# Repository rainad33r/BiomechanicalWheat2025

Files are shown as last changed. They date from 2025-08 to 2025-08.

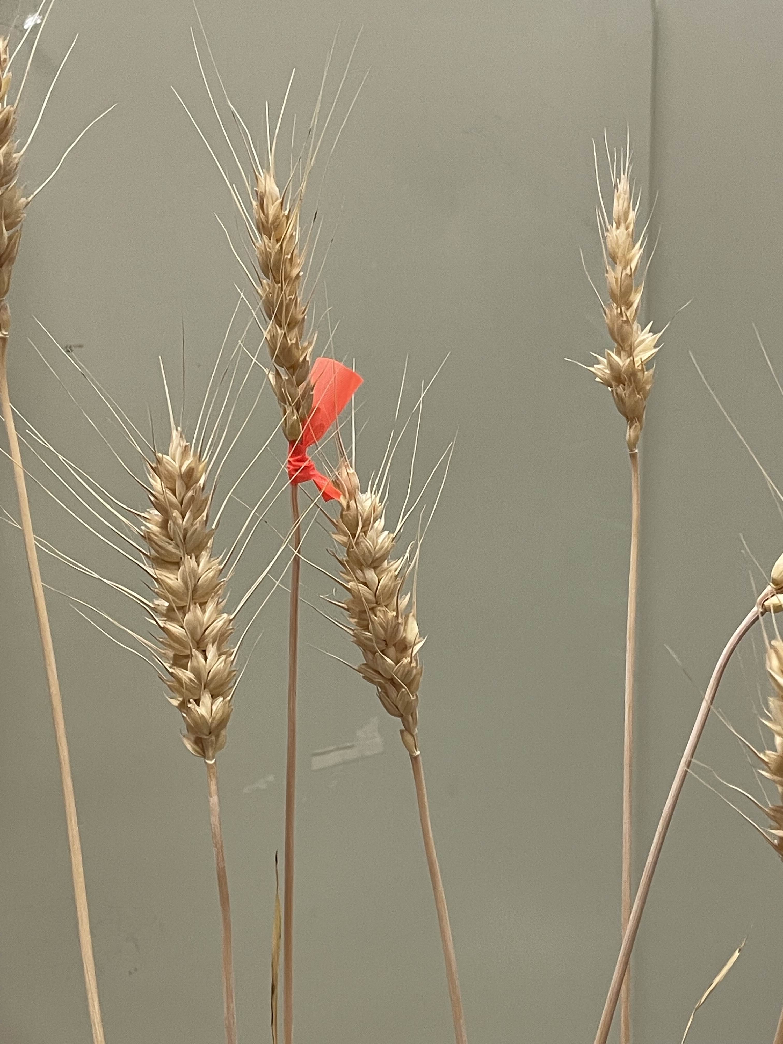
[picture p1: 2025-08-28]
Code/ColourThresholding/ImageThresholding/orangeplt.jpg

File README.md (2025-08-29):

# BiomechanicalWheat2025 USRA Repo
Compiled files of all items worked on over the summer for the wheat testing for lodging parameters. 

You can find my final poster with data from this repo [here](/FinalPoster.pdf)!

## Project Sections
Links will navigate you to specific portions of the project completed  

### Physical Design

For more information on the specifications that went into the physical design, please navigate to the [Physical Design Readme](/PhysicalDesign/README-physicalDesign.md)

> Engineering drawings and references used when modelling the full design. Many are images taken straight from my notebook. </br>[Design Files](/PhysicalDesign/DesignFiles/)

> Includes visual references for machining and STL files of the physical model </br> [Model Files (autodesk inventor)](/PhysicalDesign/modelling)

### Code

> Code used in the field with a Phidget wheatstone bridge, load cell and HUB - Python</br> [Load Cell Acquisition Code](/Code/LoadAcquistion.py)

> Code used to isolate and measure the wheat head motion - MATLAB </br>[Colour Thresholding Code](/Code/ColourThresholding)

> Code used to calculate the cross-sectional area of imaged stems (Images must have a black background to work, images captured with AMScope camera in SpecLab)</br>[Cross-Section Analysis Code](/Code/CrossSectionAnalyzer.m)

> Displays an elastic rod beam with variable damping, stiffness and applied force, code must be implemented with artisynth found [here](https://www.artisynth.org/Main/HomePage)</br>[Simulation Code](/Code/ElasticRod.java)

### Data Collected

For more information on the collected data and the possible next steps resulting from that can be found at this [ReadMe](/CollectedData/README-Data.md). 

> Data collected from the four-point bend test and cross-section analysis </br>[Material Testing](/CollectedData/MaterialsTesting)

> Analysis of material testing data</br>[Material Testing Analysis](/CollectedData/MaterialTestingAnalysis.xlsx)

> Videos and Images of the apparatus in the field </br> [Image Capture](/CollectedData/Video)

> Captured data and analysis of captred load cell data in the field </br> [Load Cell Data](/CollectedData/LoadCellTesting.xlsx)

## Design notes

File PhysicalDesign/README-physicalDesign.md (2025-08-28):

# Important!!

### This file contains helpful references for machining purposes, including size of screws, type of bars and application purposes

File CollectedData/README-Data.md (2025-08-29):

# Data Collection Review

## Image Capture

The videos captured from both the manual and cart showed promise for oscillation of the wheat, however, a few parameters of the design may need to change to for further implementation. 

1. Larger Displacement and larger barrier from external wheat. 
    - The current displacement does not push the wheat nearly as much to enforce a side-to-side oscillation (currently still very front and back) and external wheat can still break through the 'arm' and triangle barriers on the side (slip underneath) further impeding results. 
        - A thicker bar (currently 1'' thick) could be implemented and possibly improve conditions.

2. Secure the main triangle more.
    - While the triangle did work and held its own against the wheat, the frame itself was experiencing lots of motion when the cart moved along with it. 
        - This can be possibly changed with using thicker bars that extend down, rather than the 1'' bars that were used for the entire design.

3. Make variable height easier to achieve.
    - While the curent height was sufficiet for our purposes, extending the traingle and arm further down into the field may show better promise for the actual oscillation rather than the head. 

## Load Cell

Data collected by the load cell was also interesting to disect. With the main portion of the in-field collection oscillating quite a bit on a downward motion. There are a few ideals for the future use of the load cell, if it were to be used with the cart again.

1. Test the possibility of the load cell acting like an accelerometer. 
    - The cart in motion tended to show an increase on the load data collected.
        - This can be tested by simply measuring the load during a speed up and slow down test. 

2. If the load cell is acting like an accelerometer, move the cart at a slower pace. 

Finally, it was found that in combination with the side to side movement of the main design, the load cell would measure that motion as a load instead of the wheat stems. This can be possibly reduced with a more secure design as stated in the previous section.

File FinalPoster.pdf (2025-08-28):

Created by Peter Downing – Educational Media Access and Production © 2011

- Lodging occurs when too much force is exerted upon the stem of a crop, usually in the form of strong storm winds.

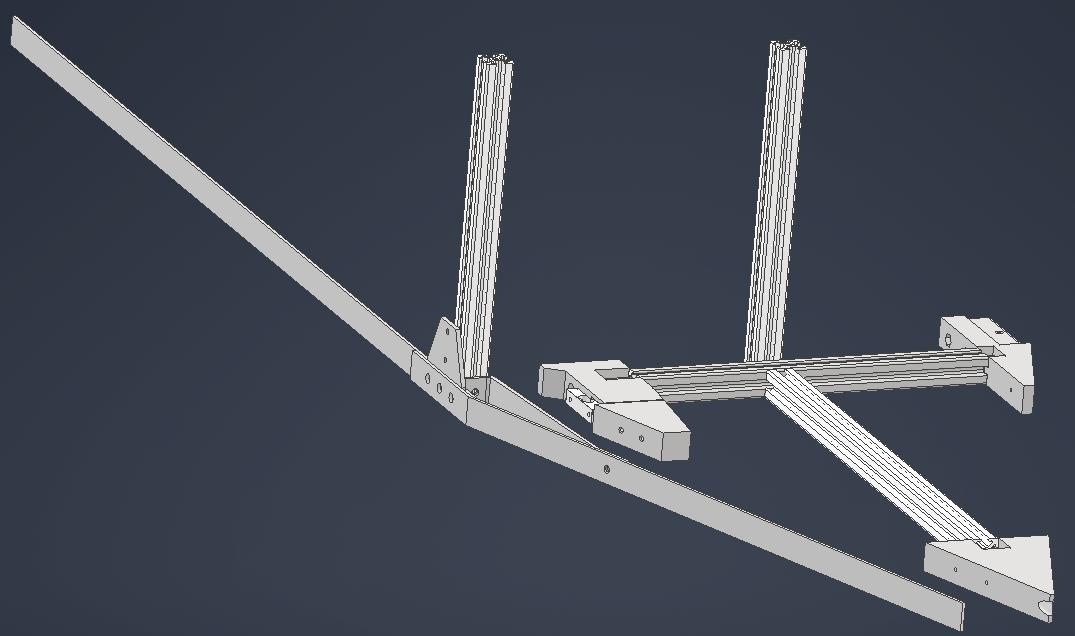
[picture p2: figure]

1-2

- To understand the factors contributing to lodging of a crop, we must first understand the biomechanics of the wheat stem
- A system is needed to measure these biomechanics

Introduction & Background

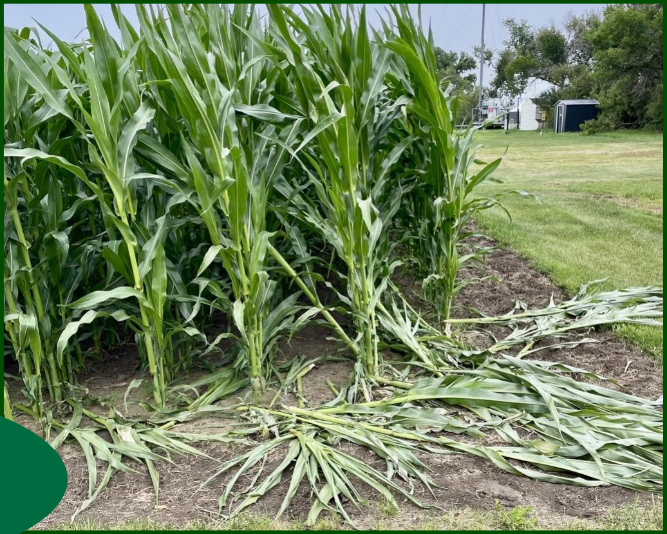
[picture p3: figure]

- To properly determine the biomechanics of wheat, two components are used: A simulation of a wheat stem with variable physical properties based on material testing, and a mechanical design used together with the Agriculture and Agri-food Canada cart in the field.
- Materials testing (four-point bend test and cross-sectional analysis) were conducted on several live and dead wheat stems to simulate varying moisture content in the crop.
- A simulation of a stem was created using the parameters found in the material testing, which could then be used to simulate oscillation of a crop.
- The mechanical design focused on perturbing the wheat a large enough distance to

Overview

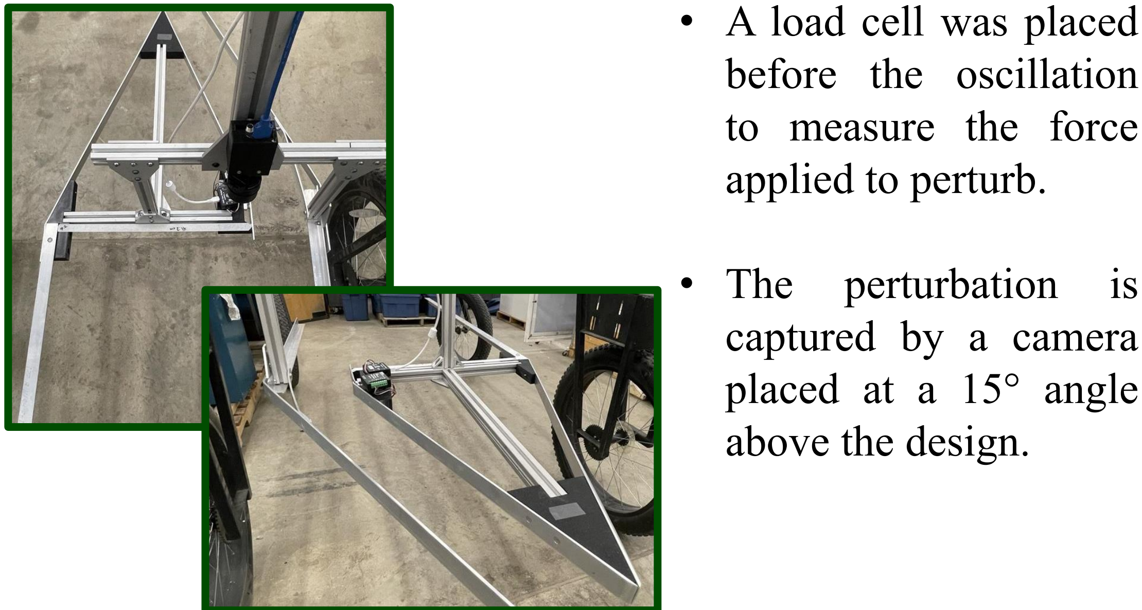
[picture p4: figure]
• A load cell was placed before the oscillation to measure the force applied to perturb.; • The; perturbation; captured by a camera placed at a 15° angle above the design.

Materials Testing

Mechanical Design | Analysis

Measured Test Oscillation Pattern

Next Steps
For future development of this research, the implementation of the mechanical design, the ‘wheat separator’, in conjunction with the AAFC cart is required for field data collection. Using the data found in the field and the previously discussed equations, a set of parameters that describe the biomechanics of wheat in the field can be developed. Comparing the field data with the simulated and test data allows for the verification of the validity of the captured data. Using the found parameters from the field in the simulation allows for the exploration of these characterizations further where variability in the physical properties of the wheat is straightforward.

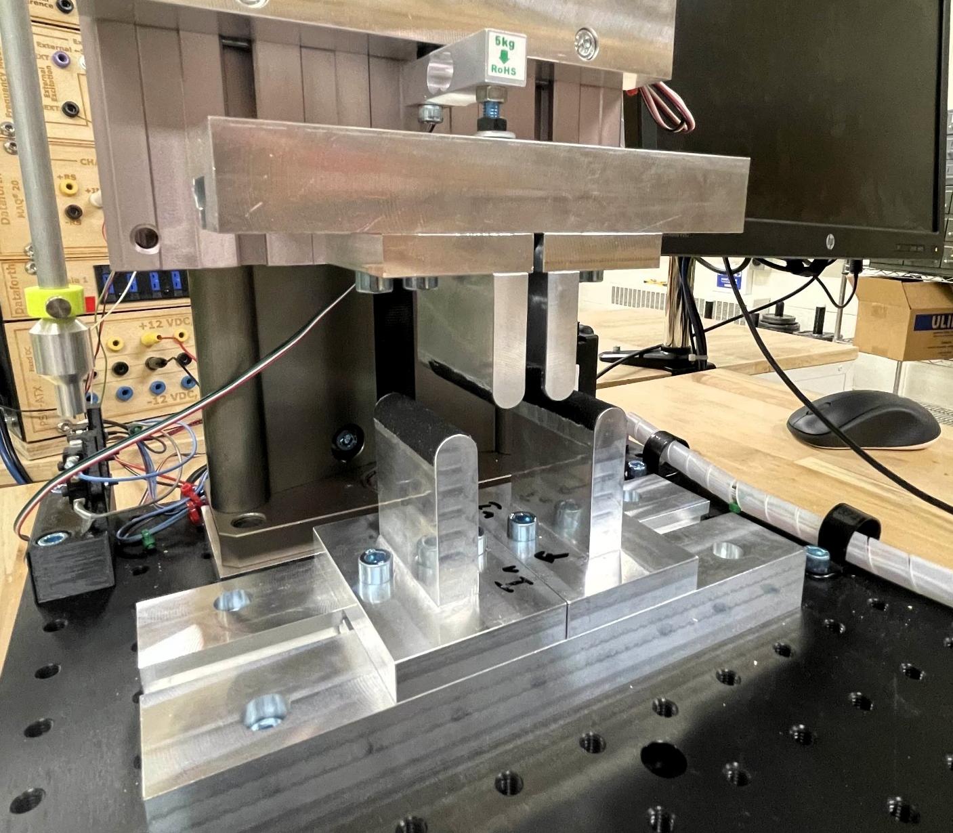
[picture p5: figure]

References

1. Sterling, M., Baker, C. J., Berry, P. M., & Wade, A. (2003a). An experimental investigation of the lodging of wheat. Agricultural and Forest Meteorology, 119(3–4), 149–165. https://doi.org/10.1016/s0168-1923(03)00140-0
2. Mohammadi, M., Finnan, J., Sterling, M., & Baker, C. (2020). A calibrated oat lodging model compared with agronomic measurements. Field Crops Research, 255, 107784. https://doi.org/10.1016/j.fcr.2020.107784
3. Dolovich, A. (2025, May). Bending of a Wheat Stem According to Euler-Bernoulli Beam Theory. Lecture.
4. O’Dogherty, M. J., Huber, J. A., Dyson, J., & Marshall, C. J. (1995). A study of the physical and mechanical properties of wheat straw. Journal of Agricultural Engineering Research, 62(2), 133–142. https://doi.org/10.1006/jaer.1995.1072

# OWL: Oscillation of Wheat to determine Lodging Parameters

# Raina Owen, Ian Stavness & Scott Noble

## Departments of Computer Science and Mechanical Engineering

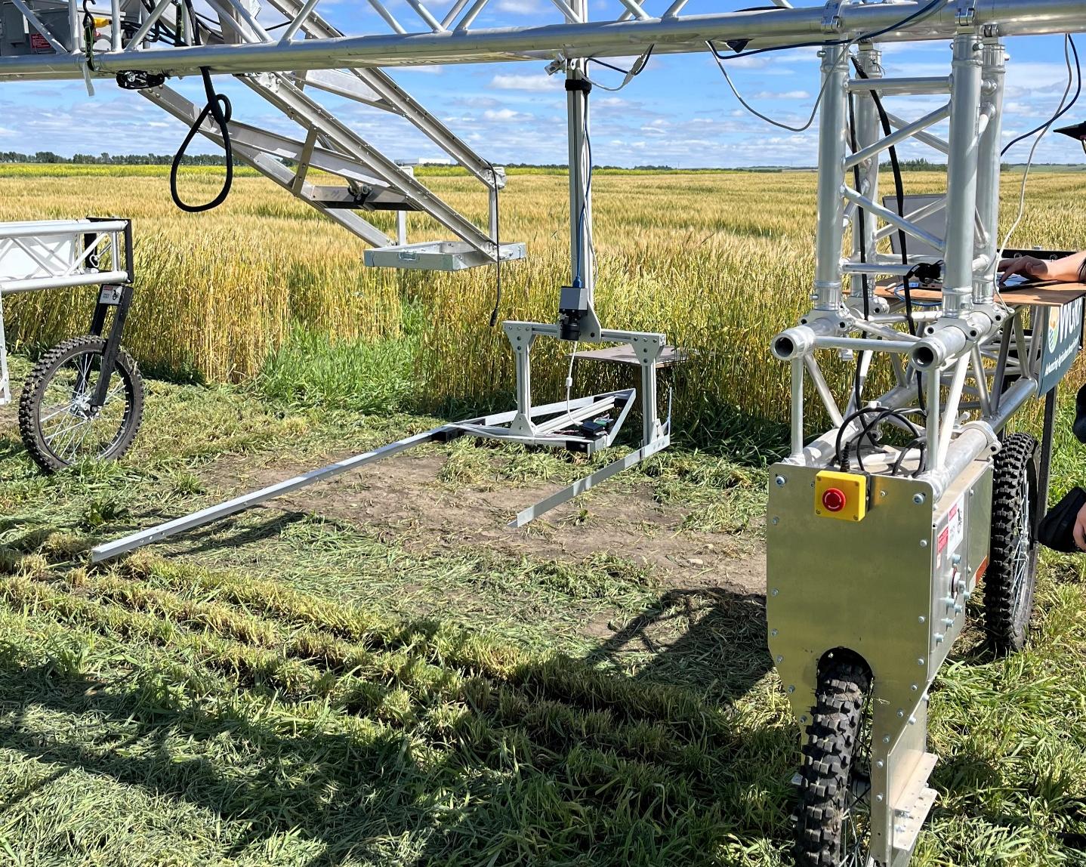
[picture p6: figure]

A cross-section of every stem that was load tested was then cut and captured with a microscope camera. This allowed us to accurately calculate the inner and outer radii of each stem.

- A 4-point bend test was
conducted to calculate the maximum stress.
- Friction tape was placed on each point to prevent
any sliding of the samples.
- Stems were tested in long sections, separated at the nodes

Simulation Capture

Example of Lodging in Corn

Cross-Sectional Capture

Four-Point Bend Test Setup

A | triangle | base
component and a
detached ‘arm’
were modelled to
contain | and
separate a select
few stems of wheat
to | simplify | the
collection of data .

Full Design of Separator

Modelled Design of Separator

Acknowledgements

Cross-Section Imaging Setup

Using the following equations, values were found for stiffness, stress and oscillation frequency.

3

Allan Dolovich – Beam theory and material testing assistance. Reisha Peters – Cross-sectional capture and analyzing assistance. Keith Halcro – General assembly and data collection support. SpecLab Team & BIGlab Team

The data found in the material testing was used to calculate stiffness and force parameters that would then be inputted into biomechanical stem model as shown below. The oscillation patterns of the design and simulation could then be compared.

But Why Care
About Lodging?

Lodged wheat is difficult to harvest and can drastically reduce the total yield.

- By exploring the
mechanics of a simulated
stem and using a
mechanical system to
capture data, the
biomechanics can be
properly determined.

k =

F
δ

=

3EI
L

3

## σmax =

4PL
πr

3

ωi =

βi

4EI
ρA

Values for modulus of elasticity and density were researched.

4

induce oscillation
while measuring the
force required to push
it to that point and
then capturing the
oscillation that
followed. The design
is made to enforce a
manageable sample
size.

AAFC Cart Attachment

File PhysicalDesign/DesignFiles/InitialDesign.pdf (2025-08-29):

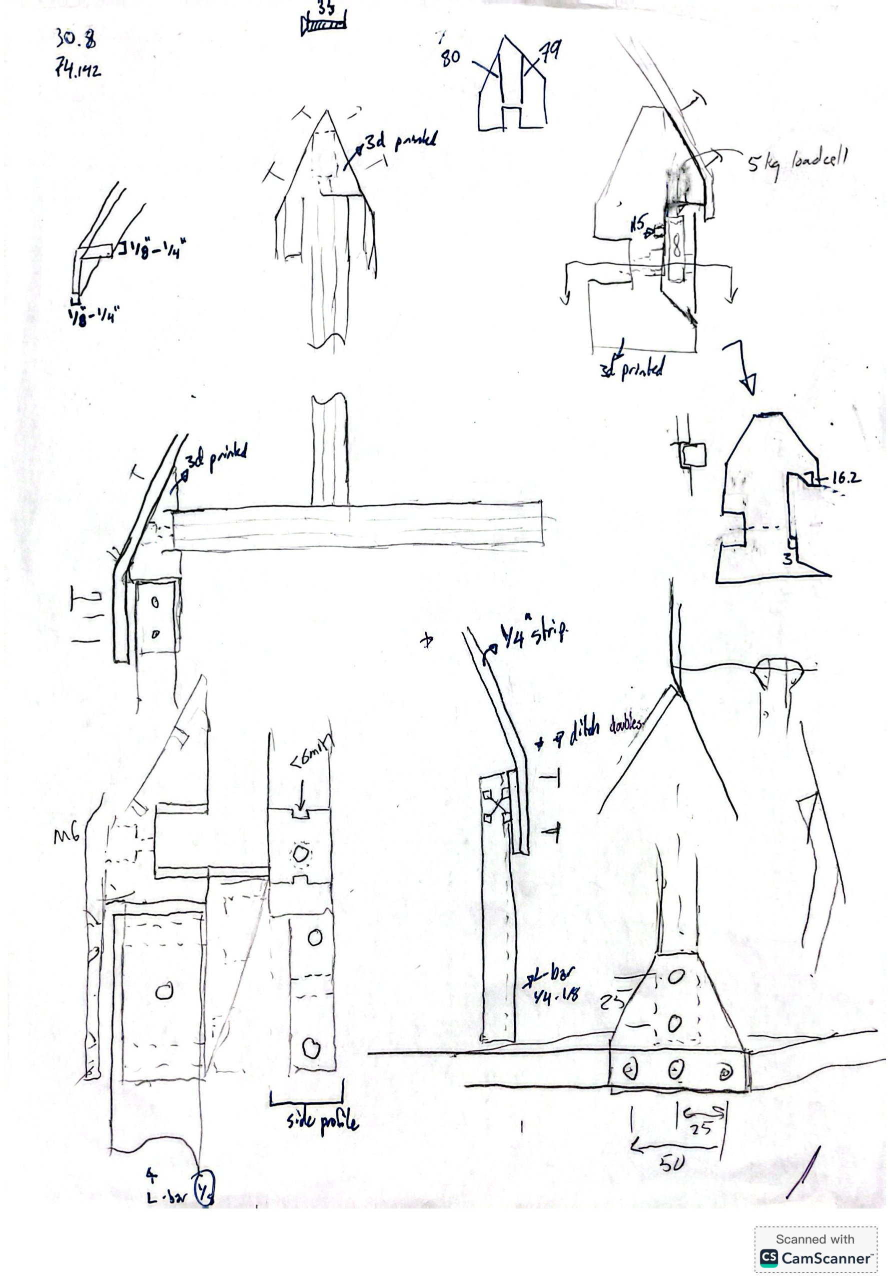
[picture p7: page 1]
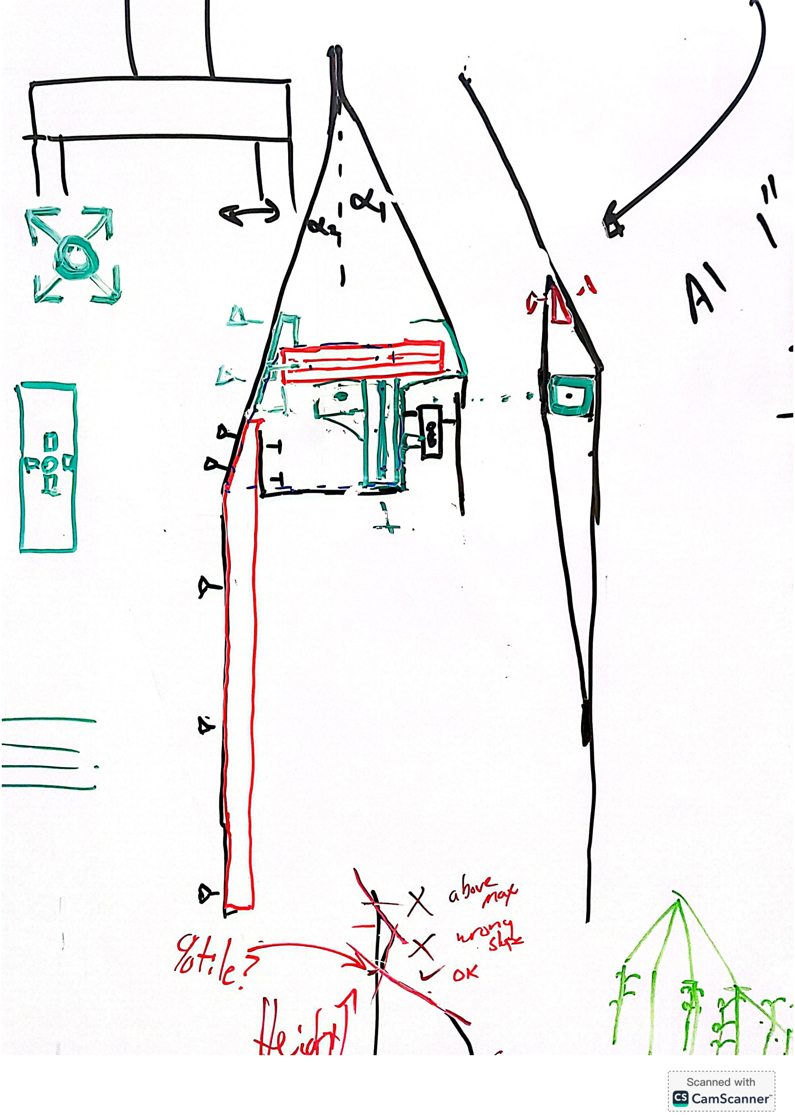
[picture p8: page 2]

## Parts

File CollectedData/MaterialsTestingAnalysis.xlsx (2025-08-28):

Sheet: DeadStems Load
Time (s) | Load Cell (N) | DeadStemLong | Time (s) | Load (N) | D105 | time | Load | D160 | time | Load | D178 | Time | Load | D258 | Time | Load | D1602 | time |  | Name: | Maximum Load
0.000 | 0.000 |  | 0.000 | 0.033 |  | 0.000 | -0.144 |  | 0.000 | 6.191 |  | 0.000 | -0.008 |  | 0.000 | -0.009 |  | 0.000 | -0.007 | D1 | 5.652
0.100 | -0.002 |  | 0.100 | 0.035 |  | 0.100 | -0.144 |  | 0.100 | 6.277 |  | 0.100 | -0.054 |  | 0.100 | -0.009 |  | 0.100 | -0.008 | DeadStemLong | 6.231
0.200 | -0.003 |  | 0.200 | 0.031 |  | 0.200 | -0.143 |  | 0.200 | 6.339 |  | 0.200 | -0.106 |  | 0.200 | 0.013 |  | 0.200 | -0.010 | D105 | 7.599
0.300 | -0.006 |  | 0.300 | 0.033 |  | 0.300 | 1.807 |  | 0.300 | 6.370 |  | 0.300 | -0.130 |  | 0.300 | -0.001 |  | 0.300 | -0.008 | D160 | 6.132
0.400 | -0.006 |  | 0.400 | 0.032 |  | 0.400 | 3.381 |  | 0.400 | 6.395 |  | 0.400 | -0.136 |  | 0.400 | -0.002 |  | 0.400 | -0.020 | D178 | 4.748
0.500 | -0.004 |  | 0.500 | 0.036 |  | 0.500 | 4.357 |  | 0.500 | 6.416 |  | 0.500 | -0.139 |  | 0.500 | -0.009 |  | 0.500 | -0.015 | D258 | 7.722
0.600 | -0.003 |  | 0.600 | 0.034 |  | 0.600 | 5.069 |  | 0.600 | 6.432 |  | 0.600 | -0.118 |  | 0.600 | -0.006 |  | 0.600 | -0.015 | D1602 | 8.507
0.700 | -0.006 |  | 0.700 | 0.038 |  | 0.700 | 5.509 |  | 0.700 | 6.444 |  | 0.700 | -0.140 |  | 0.700 | -0.004 |  | 0.700 | -0.012
0.800 | -0.004 |  | 0.800 | 0.037 |  | 0.800 | 5.830 |  | 0.800 | 6.453 |  | 0.800 | -0.141 |  | 0.800 | -0.009 |  | 0.800 | -0.014
0.900 | -0.006 |  | 0.900 | 0.038 |  | 0.900 | 6.043 |  | 0.900 | 6.454 |  | 0.900 | -0.172 |  | 0.900 | -0.009 |  | 0.900 | -0.012
1.000 | -0.004 |  | 1.000 | 0.035 |  | 1.000 | 6.173 |  | 1.000 | 6.456 |  | 1.000 | -0.184 |  | 1.000 | -0.006 |  | 1.000 | -0.009
1.100 | -0.005 |  | 1.100 | 0.038 |  | 1.100 | 6.264 |  | 1.100 | 6.456 |  | 1.100 | -0.187 |  | 1.100 | -0.009 |  | 1.100 | -0.011
1.200 | -0.005 |  | 1.200 | 0.034 |  | 1.200 | 6.325 |  | 1.200 | 6.434 |  | 1.200 | -0.195 |  | 1.200 | -0.005 |  | 1.200 | -0.009
1.300 | -0.005 |  | 1.300 | 0.035 |  | 1.300 | 6.371 |  | 1.300 | 6.443 |  | 1.300 | -0.209 |  | 1.300 | -0.006 |  | 1.300 | -0.007
1.400 | -0.005 |  | 1.400 | 0.032 |  | 1.400 | 6.397 |  | 1.400 | 6.439 |  | 1.400 | -0.230 |  | 1.400 | -0.008 |  | 1.400 | -0.004
1.500 | -0.008 |  | 1.500 | 0.036 |  | 1.500 | 6.418 |  | 1.500 | 6.424 |  | 1.500 | -0.240 |  | 1.500 | 0.005 |  | 1.500 | 0.000
1.600 | -0.006 |  | 1.600 | 0.034 |  | 1.600 | 6.437 |  | 1.600 | 6.402 |  | 1.600 | -0.259 |  | 1.600 | -0.002 |  | 1.600 | -0.007
1.700 | -0.006 |  | 1.700 | 0.036 |  | 1.700 | 6.446 |  | 1.700 | 6.371 |  | 1.700 | -0.288 |  | 1.700 | -0.003 |  | 1.700 | -0.003
1.800 | -0.007 |  | 1.800 | 0.033 |  | 1.800 | 6.453 |  | 1.800 | 6.322 |  | 1.800 | -0.308 |  | 1.800 | -0.008 |  | 1.800 | -0.004
1.900 | -0.008 |  | 1.900 | 0.036 |  | 1.900 | 6.454 |  | 1.900 | 6.254 |  | 1.900 | -0.321 |  | 1.900 | -0.004 |  | 1.900 | -0.007
2.000 | -0.006 |  | 2.000 | 0.033 |  | 2.000 | 6.456 |  | 2.000 | 6.171 |  | 2.000 | -0.341 |  | 2.000 | -0.009 |  | 2.000 | -0.005
2.100 | -0.005 |  | 2.100 | 0.034 |  | 2.100 | 6.456 |  | 2.100 | 6.057 |  | 2.100 | -0.401 |  | 2.100 | -0.020 |  | 2.100 | -0.006
2.200 | -0.006 |  | 2.200 | 0.031 |  | 2.200 | 6.453 |  | 2.200 | 5.933 |  | 2.200 | -0.421 |  | 2.200 | -0.010 |  | 2.200 | 0.007
2.300 | -0.007 |  | 2.300 | 0.033 |  | 2.300 | 6.457 |  | 2.300 | 5.775 |  | 2.300 | -0.436 |  | 2.300 | -0.015 |  | 2.300 | 0.003
2.400 | -0.007 |  | 2.400 | 0.031 |  | 2.400 | 6.455 |  | 2.400 | 5.614 |  | 2.400 | -0.454 |  | 2.400 | -0.013 |  | 2.400 | 0.000
2.500 | -0.006 |  | 2.500 | 0.032 |  | 2.500 | 6.454 |  | 2.500 | 5.416 |  | 2.500 | -0.455 |  | 2.500 | -0.008 |  | 2.500 | -0.001
2.600 | -0.005 |  | 2.600 | 0.030 |  | 2.600 | 6.455 |  | 2.600 | 5.222 |  | 2.600 | -0.467 |  | 2.600 | -0.007 |  | 2.600 | -0.003
2.700 | -0.003 |  | 2.700 | 0.033 |  | 2.700 | 6.453 |  | 2.700 | 4.991 |  | 2.700 | -0.478 |  | 2.700 | -0.006 |  | 2.700 | 0.000
2.800 | -0.005 |  | 2.800 | 0.031 |  | 2.800 | 6.457 |  | 2.800 | 4.766 |  | 2.800 | -0.493 |  | 2.800 | -0.008 |  | 2.800 | -0.003
2.900 | -0.004 |  | 2.900 | 0.034 |  | 2.900 | 6.456 |  | 2.900 | 4.510 |  | 2.900 | -0.512 |  | 2.900 | -0.007 |  | 2.900 | -0.002
3.000 | -0.004 |  | 3.000 | 0.023 |  | 3.000 | 6.459 |  | 3.000 | 4.259 |  | 3.000 | -0.529 |  | 3.000 | -0.008 |  | 3.000 | -0.004
3.100 | -0.003 |  | 3.100 | 0.011 |  | 3.100 | 6.461 |  | 3.100 | 3.983 |  | 3.100 | -0.552 |  | 3.100 | -0.013 |  | 3.100 | -0.005
3.200 | -0.003 |  | 3.200 | -0.017 |  | 3.200 | 6.457 |  | 3.200 | 3.726 |  | 3.200 | -0.578 |  | 3.200 | -0.009 |  | 3.200 | -0.004
3.300 | -0.002 |  | 3.300 | -0.087 |  | 3.300 | 6.462 |  | 3.300 | 3.439 |  | 3.300 | -0.630 |  | 3.300 | -0.014 |  | 3.300 | -0.004
3.400 | -0.003 |  | 3.400 | -0.145 |  | 3.400 | 6.460 |  | 3.400 | 3.180 |  | 3.400 | -0.655 |  | 3.400 | -0.010 |  | 3.400 | -0.002
3.500 | -0.004 |  | 3.500 | -0.230 |  | 3.500 | 6.458 |  | 3.500 | 2.890 |  | 3.500 | -0.687 |  | 3.500 | -0.008 |  | 3.500 | -0.003
3.600 | -0.004 |  | 3.600 | -0.311 |  | 3.600 | 6.459 |  | 3.600 | 2.610 |  | 3.600 | -0.752 |  | 3.600 | -0.012 |  | 3.600 | -0.005
3.700 | -0.004 |  | 3.700 | -0.403 |  | 3.700 | 6.454 |  | 3.700 | 2.343 |  | 3.700 | -0.781 |  | 3.700 | -0.007 |  | 3.700 | -0.002
3.800 | -0.005 |  | 3.800 | -0.491 |  | 3.800 | 6.455 |  | 3.800 | 2.055 |  | 3.800 | -0.810 |  | 3.800 | -0.011 |  | 3.800 | -0.006
3.900 | -0.003 |  | 3.900 | -0.589 |  | 3.900 | 6.455 |  | 3.900 | 1.787 |  | 3.900 | -0.845 |  | 3.900 | -0.008 |  | 3.900 | -0.003
4.000 | -0.001 |  | 4.000 | -0.678 |  | 4.000 | 6.450 |  | 4.000 | 1.492 |  | 4.000 | -0.911 |  | 4.000 | -0.006 |  | 4.000 | -0.003
4.100 | -0.002 |  | 4.100 | -0.781 |  | 4.100 | 6.453 |  | 4.100 | 1.225 |  | 4.100 | -0.948 |  | 4.100 | -0.009 |  | 4.100 | -0.004
4.200 | -0.003 |  | 4.200 | -0.882 |  | 4.200 | 6.446 |  | 4.200 | 0.932 |  | 4.200 | -1.060 |  | 4.200 | -0.006 |  | 4.200 | -0.003
4.300 | -0.003 |  | 4.300 | -0.969 |  | 4.300 | 6.448 |  | 4.300 | 0.667 |  | 4.300 | -1.142 |  | 4.300 | -0.009 |  | 4.300 | -0.009
4.400 | -0.004 |  | 4.400 | -1.075 |  | 4.400 | 6.449 |  | 4.400 | 0.377 |  | 4.400 | -1.182 |  | 4.400 | -0.011 |  | 4.400 | -0.010
4.500 | -0.002 |  | 4.500 | -1.178 |  | 4.500 | 6.448 |  | 4.500 | 0.116 |  | 4.500 | -1.226 |  | 4.500 | -0.008 |  | 4.500 | -0.012
4.600 | -0.001 |  | 4.600 | -1.284 |  | 4.600 | 6.448 |  | 4.600 | -0.153 |  | 4.600 | -1.268 |  | 4.600 | -0.014 |  | 4.600 | -0.015
4.700 | -0.003 |  | 4.700 | -1.389 |  | 4.700 | 6.444 |  | 4.700 | -0.409 |  | 4.700 | -1.316 |  | 4.700 | -0.013 |  | 4.700 | -0.016
4.800 | -0.002 |  | 4.800 | -1.495 |  | 4.800 | 6.444 |  | 4.800 | -0.676 |  | 4.800 | -1.410 |  | 4.800 | -0.022 |  | 4.800 | -0.024
4.900 | -0.002 |  | 4.900 | -1.599 |  | 4.900 | 6.444 |  | 4.900 | -0.925 |  | 4.900 | -1.454 |  | 4.900 | -0.036 |  | 4.900 | -0.032
5.000 | -0.002 |  | 5.000 | -1.711 |  | 5.000 | 6.444 |  | 5.000 | -1.194 |  | 5.000 | -1.501 |  | 5.000 | -0.046 |  | 5.000 | -0.046
5.100 | -0.002 |  | 5.100 | -1.826 |  | 5.100 | 6.437 |  | 5.100 | -1.430 |  | 5.100 | -1.549 |  | 5.100 | -0.069 |  | 5.100 | -0.066
5.200 | -0.003 |  | 5.200 | -1.932 |  | 5.200 | 6.430 |  | 5.200 | -1.694 |  | 5.200 | -1.598 |  | 5.200 | -0.091 |  | 5.200 | -0.083
5.300 | -0.003 |  | 5.300 | -2.035 |  | 5.300 | 6.431 |  | 5.300 | -1.922 |  | 5.300 | -1.650 |  | 5.300 | -0.121 |  | 5.300 | -0.112
5.400 | -0.004 |  | 5.400 | -2.157 |  | 5.400 | 6.426 |  | 5.400 | -2.170 |  | 5.400 | -1.703 |  | 5.400 | -0.161 |  | 5.400 | -0.143
5.500 | -0.004 |  | 5.500 | -2.270 |  | 5.500 | 6.426 |  | 5.500 | -2.406 |  | 5.500 | -1.753 |  | 5.500 | -0.195 |  | 5.500 | -0.174
5.600 | -0.004 |  | 5.600 | -2.381 |  | 5.600 | 6.420 |  | 5.600 | -2.614 |  | 5.600 | -1.859 |  | 5.600 | -0.242 |  | 5.600 | -0.218
5.700 | -0.001 |  | 5.700 | -2.496 |  | 5.700 | 6.405 |  | 5.700 | -2.845 |  | 5.700 | -1.913 |  | 5.700 | -0.291 |  | 5.700 | -0.258
5.800 | -0.004 |  | 5.800 | -2.609 |  | 5.800 | 6.404 |  | 5.800 | -3.046 |  | 5.800 | -1.966 |  | 5.800 | -0.346 |  | 5.800 | -0.301
5.900 | -0.004 |  | 5.900 | -2.737 |  | 5.900 | 6.397 |  | 5.900 | -3.247 |  | 5.900 | -2.015 |  | 5.900 | -0.407 |  | 5.900 | -0.351
6.000 | -0.004 |  | 6.000 | -2.904 |  | 6.000 | 6.391 |  | 6.000 | -3.457 |  | 6.000 | -2.069 |  | 6.000 | -0.473 |  | 6.000 | -0.410
6.100 | -0.002 |  | 6.100 | -3.002 |  | 6.100 | 6.388 |  | 6.100 | -3.641 |  | 6.100 | -2.119 |  | 6.100 | -0.540 |  | 6.100 | -0.473
6.200 | 0.000 |  | 6.200 | -3.084 |  | 6.200 | 6.374 |  | 6.200 | -3.842 |  | 6.200 | -2.285 |  | 6.200 | -0.615 |  | 6.200 | -0.554
6.300 | 0.000 |  | 6.300 | -3.180 |  | 6.300 | 6.365 |  | 6.300 | -4.013 |  | 6.300 | -2.336 |  | 6.300 | -0.686 |  | 6.300 | -0.637
6.400 | -0.001 |  | 6.400 | -3.274 |  | 6.400 | 6.348 |  | 6.400 | -4.193 |  | 6.400 | -2.392 |  | 6.400 | -0.771 |  | 6.400 | -0.731
6.500 | 0.000 |  | 6.500 | -3.368 |  | 6.500 | 6.340 |  | 6.500 | -4.363 |  | 6.500 | -2.443 |  | 6.500 | -0.847 |  | 6.500 | -0.841
6.600 | -0.002 |  | 6.600 | -3.468 |  | 6.600 | 6.329 |  | 6.600 | -4.508 |  | 6.600 | -2.494 |  | 6.600 | -0.938 |  | 6.600 | -0.959
6.700 | -0.002 |  | 6.700 | -3.567 |  | 6.700 | 6.314 |  | 6.700 | -4.663 |  | 6.700 | -2.558 |  | 6.700 | -1.021 |  | 6.700 | -1.077
6.800 | -0.003 |  | 6.800 | -3.675 |  | 6.800 | 6.303 |  | 6.800 | -4.792 |  | 6.800 | -2.613 |  | 6.800 | -1.117 |  | 6.800 | -1.210
6.900 | -0.002 |  | 6.900 | -3.768 |  | 6.900 | 6.284 |  | 6.900 | -4.931 |  | 6.900 | -2.676 |  | 6.900 | -1.212 |  | 6.900 | -1.340
7.000 | -0.004 |  | 7.000 | -3.876 |  | 7.000 | 6.265 |  | 7.000 | -5.051 |  | 7.000 | -2.732 |  | 7.000 | -1.310 |  | 7.000 | -1.490
7.100 | -0.005 |  | 7.100 | -3.967 |  | 7.100 | 6.257 |  | 7.100 | -5.180 |  | 7.100 | -2.793 |  | 7.100 | -1.403 |  | 7.100 | -1.627
7.200 | -0.005 |  | 7.200 | -4.071 |  | 7.200 | 6.244 |  | 7.200 | -5.289 |  | 7.200 | -2.908 |  | 7.200 | -1.506 |  | 7.200 | -1.785
7.300 | -0.004 |  | 7.300 | -4.167 |  | 7.300 | 6.237 |  | 7.300 | -5.393 |  | 7.300 | -2.960 |  | 7.300 | -1.601 |  | 7.300 | -1.933
7.400 | -0.001 |  | 7.400 | -4.262 |  | 7.400 | 6.232 |  | 7.400 | -5.484 |  | 7.400 | -3.018 |  | 7.400 | -1.707 |  | 7.400 | -2.090
7.500 | -0.003 |  | 7.500 | -4.362 |  | 7.500 | 6.222 |  | 7.500 | -5.569 |  | 7.500 | -3.075 |  | 7.500 | -1.807 |  | 7.500 | -2.243
7.600 | -0.003 |  | 7.600 | -4.451 |  | 7.600 | 6.222 |  | 7.600 | -5.647 |  | 7.600 | -3.193 |  | 7.600 | -1.916 |  | 7.600 | -2.403
7.700 | -0.002 |  | 7.700 | -4.556 |  | 7.700 | 6.213 |  | 7.700 | -5.726 |  | 7.700 | -3.249 |  | 7.700 | -2.025 |  | 7.700 | -2.559
7.800 | -0.002 |  | 7.800 | -4.639 |  | 7.800 | 6.202 |  | 7.800 | -5.791 |  | 7.800 | -3.306 |  | 7.800 | -2.129 |  | 7.800 | -2.730
7.900 | 0.000 |  | 7.900 | -4.737 |  | 7.900 | 6.179 |  | 7.900 | -5.852 |  | 7.900 | -3.368 |  | 7.900 | -2.238 |  | 7.900 | -2.882
8.000 | 0.002 |  | 8.000 | -4.826 |  | 8.000 | 6.147 |  | 8.000 | -5.896 |  | 8.000 | -3.421 |  | 8.000 | -2.344 |  | 8.000 | -3.065
8.100 | 0.000 |  | 8.100 | -4.914 |  | 8.100 | 6.117 |  | 8.100 | -5.938 |  | 8.100 | -3.478 |  | 8.100 | -2.459 |  | 8.100 | -3.222
8.200 | 0.000 |  | 8.200 | -5.008 |  | 8.200 | 6.076 |  | 8.200 | -5.975 |  | 8.200 | -3.528 |  | 8.200 | -2.564 |  | 8.200 | -3.407
8.300 | -0.001 |  | 8.300 | -5.090 |  | 8.300 | 6.036 |  | 8.300 | -6.008 |  | 8.300 | -3.582 |  | 8.300 | -2.689 |  | 8.300 | -3.585
8.400 | -0.002 |  | 8.400 | -5.175 |  | 8.400 | 5.986 |  | 8.400 | -6.052 |  | 8.400 | -3.640 |  | 8.400 | -2.798 |  | 8.400 | -3.755
8.500 | -0.002 |  | 8.500 | -5.269 |  | 8.500 | 5.927 |  | 8.500 | -6.079 |  | 8.500 | -3.694 |  | 8.500 | -2.905 |  | 8.500 | -3.944
8.600 | -0.003 |  | 8.600 | -5.341 |  | 8.600 | 5.861 |  | 8.600 | -6.105 |  | 8.600 | -3.804 |  | 8.600 | -3.013 |  | 8.600 | -4.116
8.700 | -0.001 |  | 8.700 | -5.434 |  | 8.700 | 5.790 |  | 8.700 | -6.122 |  | 8.700 | -3.914 |  | 8.700 | -3.118 |  | 8.700 | -4.307
8.800 | -0.002 |  | 8.800 | -5.503 |  | 8.800 | 5.707 |  | 8.800 | -6.131 |  | 8.800 | -3.967 |  | 8.800 | -3.226 |  | 8.800 | -4.469
8.900 | -0.002 |  | 8.900 | -5.588 |  | 8.900 | 5.626 |  | 8.900 | -6.132 |  | 8.900 | -4.075 |  | 8.900 | -3.339 |  | 8.900 | -4.655
9.000 | -0.002 |  | 9.000 | -5.650 |  | 9.000 | 5.536 |  | 9.000 | -6.123 |  | 9.000 | -4.124 |  | 9.000 | -3.442 |  | 9.000 | -4.819
9.100 | -0.002 |  | 9.100 | -5.718 |  | 9.100 | 5.449 |  | 9.100 | -6.104 |  | 9.100 | -4.220 |  | 9.100 | -3.559 |  | 9.100 | -4.991
9.200 | -0.001 |  | 9.200 | -5.784 |  | 9.200 | 5.353 |  | 9.200 | -6.069 |  | 9.200 | -4.315 |  | 9.200 | -3.661 |  | 9.200 | -5.154
9.300 | -0.001 |  | 9.300 | -5.842 |  | 9.300 | 5.259 |  | 9.300 | -6.031 |  | 9.300 | -4.400 |  | 9.300 | -3.787 |  | 9.300 | -5.322
9.400 | -0.002 |  | 9.400 | -5.907 |  | 9.400 | 5.166 |  | 9.400 | -5.988 |  | 9.400 | -4.481 |  | 9.400 | -3.895 |  | 9.400 | -5.487
9.500 | -0.003 |  | 9.500 | -5.953 |  | 9.500 | 5.066 |  | 9.500 | -5.938 |  | 9.500 | -4.516 |  | 9.500 | -4.014 |  | 9.500 | -5.664
9.600 | -0.005 |  | 9.600 | -6.010 |  | 9.600 | 4.981 |  | 9.600 | -5.890 |  | 9.600 | -4.556 |  | 9.600 | -4.131 |  | 9.600 | -5.821
9.700 | -0.006 |  | 9.700 | -6.035 |  | 9.700 | 4.927 |  | 9.700 | -5.841 |  | 9.700 | -4.584 |  | 9.700 | -4.245 |  | 9.700 | -5.994
9.800 | -0.005 |  | 9.800 | -6.080 |  | 9.800 | 4.896 |  | 9.800 | -5.790 |  | 9.800 | -4.623 |  | 9.800 | -4.361 |  | 9.800 | -6.141
9.900 | -0.004 |  | 9.900 | -6.112 |  | 9.900 | 4.879 |  | 9.900 | -5.746 |  | 9.900 | -4.641 |  | 9.900 | -4.483 |  | 9.900 | -6.308
10.000 | -0.002 |  | 10.000 | -6.142 |  | 10.000 | 4.872 |  | 10.000 | -5.696 |  | 10.000 | -4.679 |  | 10.000 | -4.589 |  | 10.000 | -6.450
10.100 | -0.003 |  | 10.100 | -6.176 |  | 10.100 | 4.866 |  | 10.100 | -5.650 |  | 10.100 | -4.692 |  | 10.100 | -4.714 |  | 10.100 | -6.603
10.200 | -0.003 |  | 10.200 | -6.193 |  | 10.200 | 4.864 |  | 10.200 | -5.601 |  | 10.200 | -4.709 |  | 10.200 | -4.821 |  | 10.200 | -6.751
10.300 | -0.003 |  | 10.300 | -6.218 |  | 10.300 | 4.869 |  | 10.300 | -5.561 |  | 10.300 | -4.720 |  | 10.300 | -4.942 |  | 10.300 | -6.881
10.400 | -0.002 |  | 10.400 | -6.222 |  | 10.400 | 4.870 |  | 10.400 | -5.520 |  | 10.400 | -4.730 |  | 10.400 | -5.053 |  | 10.400 | -7.025
10.500 | 0.000 |  | 10.500 | -6.231 |  | 10.500 | 4.874 |  | 10.500 | -5.467 |  | 10.500 | -4.740 |  | 10.500 | -5.160 |  | 10.500 | -7.147
10.600 | -0.001 |  | 10.600 | -6.222 |  | 10.600 | 4.910 |  | 10.600 | -5.413 |  | 10.600 | -4.742 |  | 10.600 | -5.272 |  | 10.600 | -7.280
10.700 | -0.002 |  | 10.700 | -6.204 |  | 10.700 | 4.971 |  | 10.700 | -5.361 |  | 10.700 | -4.748 |  | 10.700 | -5.376 |  | 10.700 | -7.393
10.800 | -0.002 |  | 10.800 | -6.182 |  | 10.800 | 5.063 |  | 10.800 | -5.301 |  | 10.800 | -4.736 |  | 10.800 | -5.483 |  | 10.800 | -7.517
10.900 | -0.004 |  | 10.900 | -6.134 |  | 10.900 | 5.167 |  | 10.900 | -5.260 |  | 10.900 | -4.714 |  | 10.900 | -5.595 |  | 10.900 | -7.631
11.000 | -0.002 |  | 11.000 | -6.098 |  | 11.000 | 5.277 |  | 11.000 | -5.217 |  | 11.000 | -4.608 |  | 11.000 | -5.696 |  | 11.000 | -7.742
11.100 | -0.002 |  | 11.100 | -6.037 |  | 11.100 | 5.400 |  | 11.100 | -5.186 |  | 11.100 | -4.588 |  | 11.100 | -5.812 |  | 11.100 | -7.847
11.200 | -0.001 |  | 11.200 | -5.985 |  | 11.200 | 5.513 |  | 11.200 | -5.137 |  | 11.200 | -4.524 |  | 11.200 | -5.907 |  | 11.200 | -7.946
11.300 | 0.000 |  | 11.300 | -5.923 |  | 11.300 | 5.640 |  | 11.300 | -5.093 |  | 11.300 | -4.499 |  | 11.300 | -6.021 |  | 11.300 | -8.030
11.400 | -0.001 |  | 11.400 | -5.853 |  | 11.400 | 5.751 |  | 11.400 | -5.051 |  | 11.400 | -4.481 |  | 11.400 | -6.123 |  | 11.400 | -8.121
11.500 | -0.011 |  | 11.500 | -5.792 |  | 11.500 | 5.868 |  | 11.500 | -5.011 |  | 11.500 | -4.455 |  | 11.500 | -6.218 |  | 11.500 | -8.186
11.600 | -0.021 |  | 11.600 | -5.726 |  | 11.600 | 5.973 |  | 11.600 | -4.976 |  | 11.600 | -4.443 |  | 11.600 | -6.317 |  | 11.600 | -8.261
11.700 | -0.056 |  | 11.700 | -5.667 |  | 11.700 | 6.072 |  | 11.700 | -4.944 |  | 11.700 | -4.423 |  | 11.700 | -6.407 |  | 11.700 | -8.313
11.800 | -0.119 |  | 11.800 | -5.612 |  | 11.800 | 6.157 |  | 11.800 | -4.908 |  | 11.800 | -4.400 |  | 11.800 | -6.498 |  | 11.800 | -8.369
11.900 | -0.182 |  | 11.900 | -5.558 |  | 11.900 | 6.232 |  | 11.900 | -4.881 |  | 11.900 | -4.388 |  | 11.900 | -6.593 |  | 11.900 | -8.409
12.000 | -0.250 |  | 12.000 | -5.504 |  | 12.000 | 6.292 |  | 12.000 | -4.849 |  | 12.000 | -4.384 |  | 12.000 | -6.673 |  | 12.000 | -8.449
12.100 | -0.329 |  | 12.100 | -5.454 |  | 12.100 | 6.352 |  | 12.100 | -4.830 |  | 12.100 | -4.372 |  | 12.100 | -6.766 |  | 12.100 | -8.481
12.200 | -0.406 |  | 12.200 | -5.406 |  | 12.200 | 6.385 |  | 12.200 | -4.805 |  | 12.200 | -4.370 |  | 12.200 | -6.843 |  | 12.200 | -8.498
12.300 | -0.488 |  | 12.300 | -5.352 |  | 12.300 | 6.415 |  | 12.300 | -4.772 |  | 12.300 | -4.362 |  | 12.300 | -6.919 |  | 12.300 | -8.507
12.400 | -0.565 |  | 12.400 | -5.303 |  | 12.400 | 6.430 |  | 12.400 | -4.734 |  | 12.400 | -4.351 |  | 12.400 | -6.988 |  | 12.400 | -8.503
12.500 | -0.644 |  | 12.500 | -5.246 |  | 12.500 | 6.439 |  | 12.500 | -4.676 |  | 12.500 | -4.346 |  | 12.500 | -7.052 |  | 12.500 | -8.487
12.600 | -0.722 |  | 12.600 | -5.182 |  | 12.600 | 6.448 |  | 12.600 | -4.574 |  | 12.600 | -4.336 |  | 12.600 | -7.119 |  | 12.600 | -8.469
12.700 | -0.808 |  | 12.700 | -5.122 |  | 12.700 | 6.449 |  | 12.700 | -4.443 |  | 12.700 | -4.330 |  | 12.700 | -7.173 |  | 12.700 | -8.444
12.800 | -0.883 |  | 12.800 | -5.053 |  | 12.800 | 6.454 |  | 12.800 | -4.307 |  | 12.800 | -4.323 |  | 12.800 | -7.241 |  | 12.800 | -8.421
12.900 | -0.974 |  | 12.900 | -5.007 |  | 12.900 | 4.401 |  | 12.900 | -4.100 |  | 12.900 | -4.316 |  | 12.900 | -7.296 |  | 12.900 | -8.390
13.000 | -1.053 |  | 13.000 | -4.948 |  | 13.000 | 2.994 |  | 13.000 | -3.861 |  | 13.000 | -4.308 |  | 13.000 | -7.352 |  | 13.000 | -8.365
13.100 | -1.141 |  | 13.100 | -4.902 |  | 13.100 | 1.974 |  | 13.100 | -3.601 |  | 13.100 | -4.299 |  | 13.100 | -7.410 |  | 13.100 | -8.343
13.200 | -1.222 |  | 13.200 | -4.832 |  | 13.200 | 1.337 |  | 13.200 | -3.356 |  | 13.200 | -4.295 |  | 13.200 | -7.455 |  | 13.200 | -8.317
13.300 | -1.304 |  | 13.300 | -4.765 |  | 13.300 | 0.874 |  | 13.300 | -3.143 |  | 13.300 | -4.284 |  | 13.300 | -7.506 |  | 13.300 | -8.302
13.400 | -1.385 |  | 13.400 | -4.707 |  | 13.400 | 0.588 |  | 13.400 | -3.014 |  | 13.400 | -4.280 |  | 13.400 | -7.548 |  | 13.400 | -8.278
13.500 | -1.468 |  | 13.500 | -4.645 |  | 13.500 | 0.369 |  | 13.500 | -2.919 |  | 13.500 | -4.267 |  | 13.500 | -7.584 |  | 13.500 | -8.257
13.600 | -1.549 |  | 13.600 | -4.605 |  | 13.600 | 0.238 |  | 13.600 | -2.854 |  | 13.600 | -4.244 |  | 13.600 | -7.620 |  | 13.600 | -8.232
13.700 | -1.630 |  | 13.700 | -4.553 |  | 13.700 | 0.141 |  | 13.700 | -2.797 |  | 13.700 | -4.197 |  | 13.700 | -7.642 |  | 13.700 | -8.201
13.800 | -1.713 |  | 13.800 | -4.519 |  | 13.800 | 0.078 |  | 13.800 | -2.758 |  | 13.800 | -4.144 |  | 13.800 | -7.671 |  | 13.800 | -8.176
13.900 | -1.794 |  | 13.900 | -4.479 |  | 13.900 | 2.094 |  | 13.900 | -2.736 |  | 13.900 | -4.096 |  | 13.900 | -7.686 |  | 13.900 | -8.139
14.000 | -1.873 |  | 14.000 | -4.444 |  | 14.000 | 3.474 |  | 14.000 | -2.753 |  | 14.000 | -4.050 |  | 14.000 | -7.702 |  | 14.000 | -8.106
14.100 | -1.956 |  | 14.100 | -4.411 |  | 14.100 | 4.482 |  | 14.100 | -2.846 |  | 14.100 | -3.965 |  | 14.100 | -7.715 |  | 14.100 | -8.068
14.200 | -2.046 |  | 14.200 | -4.380 |  | 14.200 | 5.106 |  | 14.200 | -2.963 |  | 14.200 | -3.930 |  | 14.200 | -7.718 |  | 14.200 | -8.000
14.300 | -2.123 |  | 14.300 | -4.353 |  | 14.300 | 5.562 |  | 14.300 | -3.118 |  | 14.300 | -3.897 |  | 14.300 | -7.722 |  | 14.300 | -7.930
14.400 | -2.213 |  | 14.400 | -4.327 |  | 14.400 | 5.843 |  | 14.400 | -3.267 |  | 14.400 | -3.868 |  | 14.400 | -7.711 |  | 14.400 | -7.865
14.500 | -2.298 |  | 14.500 | -4.303 |  | 14.500 | 6.050 |  | 14.500 | -3.428 |  | 14.500 | -3.841 |  | 14.500 | -7.686 |  | 14.500 | -7.804
14.600 | -2.392 |  | 14.600 | -4.279 |  | 14.600 | 6.183 |  | 14.600 | -3.570 |  | 14.600 | -3.816 |  | 14.600 | -7.662 |  | 14.600 | -7.751
14.700 | -2.471 |  | 14.700 | -4.255 |  | 14.700 | 6.280 |  | 14.700 | -3.706 |  | 14.700 | -3.792 |  | 14.700 | -7.619 |  | 14.700 | -7.698
14.800 | -2.557 |  | 14.800 | -4.234 |  | 14.800 | 6.342 |  | 14.800 | -3.816 |  | 14.800 | -3.771 |  | 14.800 | -7.558 |  | 14.800 | -7.655
14.900 | -2.642 |  | 14.900 | -4.207 |  | 14.900 | 6.378 |  | 14.900 | -3.901 |  | 14.900 | -3.750 |  | 14.900 | -7.487 |  | 14.900 | -7.616
15.000 | -2.728 |  | 15.000 | -4.189 |  | 15.000 | 6.401 |  | 15.000 | -3.967 |  | 15.000 | -3.733 |  | 15.000 | -7.404 |  | 15.000 | -7.587
15.100 | -2.812 |  | 15.100 | -4.159 |  | 15.100 | 6.419 |  | 15.100 | -4.020 |  | 15.100 | -3.714 |  | 15.100 | -7.311 |  | 15.100 | -7.551
15.200 | -2.901 |  | 15.200 | -4.136 |  | 15.200 | 6.431 |  | 15.200 | -4.041 |  | 15.200 | -3.697 |  | 15.200 | -7.222 |  | 15.200 | -7.519
15.300 | -2.982 |  | 15.300 | -4.107 |  | 15.300 | 6.447 |  | 15.300 | -4.057 |  | 15.300 | -3.670 |  | 15.300 | -7.131 |  | 15.300 | -7.485
15.400 | -3.077 |  | 15.400 | -4.078 |  | 15.400 | 6.455 |  | 15.400 | -4.057 |  | 15.400 | -3.604 |  | 15.400 | -7.043 |  | 15.400 | -7.445
15.500 | -3.151 |  | 15.500 | -4.058 |  | 15.500 | 6.460 |  | 15.500 | -4.051 |  | 15.500 | -3.434 |  | 15.500 | -6.970 |  | 15.500 | -7.414
15.600 | -3.240 |  | 15.600 | -4.023 |  | 15.600 | 6.463 |  | 15.600 | -4.039 |  | 15.600 | -3.341 |  | 15.600 | -6.892 |  | 15.600 | -7.377
15.700 | -3.322 |  | 15.700 | -4.001 |  | 15.700 | 6.464 |  | 15.700 | -4.015 |  | 15.700 | -3.253 |  | 15.700 | -6.823 |  | 15.700 | -7.345
15.800 | -3.401 |  | 15.800 | -3.965 |  | 15.800 | 6.457 |  | 15.800 | -3.996 |  | 15.800 | -3.162 |  | 15.800 | -6.762 |  | 15.800 | -7.309
15.900 | -3.483 |  | 15.900 | -3.937 |  | 15.900 | 6.458 |  | 15.900 | -3.967 |  | 15.900 | -3.082 |  | 15.900 | -6.694 |  | 15.900 | -7.266
16.000 | -3.552 |  | 16.000 | -3.911 |  | 16.000 | 6.455 |  | 16.000 | -3.942 |  | 16.000 | -2.998 |  | 16.000 | -6.626 |  | 16.000 | -7.212
16.100 | -3.629 |  | 16.100 | -3.877 |  | 16.100 | 6.460 |  | 16.100 | -3.913 |  | 16.100 | -2.927 |  | 16.100 | -6.567 |  | 16.100 | -7.155
16.200 | -3.698 |  | 16.200 | -3.853 |  | 16.200 | 6.471 |  | 16.200 | -3.876 |  | 16.200 | -2.781 |  | 16.200 | -6.503 |  | 16.200 | -7.100
16.300 | -3.775 |  | 16.300 | -3.819 |  | 16.300 | 6.470 |  | 16.300 | -3.834 |  | 16.300 | -2.650 |  | 16.300 | -6.457 |  | 16.300 | -7.049
16.400 | -3.840 |  | 16.400 | -3.795 |  | 16.400 | 6.468 |  | 16.400 | -3.777 |  | 16.400 | -2.593 |  | 16.400 | -6.412 |  | 16.400 | -6.994
16.500 | -3.917 |  | 16.500 | -3.760 |  | 16.500 | 6.467 |  | 16.500 | -3.732 |  | 16.500 | -2.480 |  | 16.500 | -6.378 |  | 16.500 | -6.955
16.600 | -3.986 |  | 16.600 | -3.732 |  | 16.600 | 6.465 |  | 16.600 | -3.677 |  | 16.600 | -2.424 |  | 16.600 | -6.341 |  | 16.600 | -6.912
16.700 | -4.056 |  | 16.700 | -3.705 |  | 16.700 | 6.461 |  | 16.700 | -3.628 |  | 16.700 | -2.378 |  | 16.700 | -6.308 |  | 16.700 | -6.879
16.800 | -4.123 |  | 16.800 | -3.675 |  | 16.800 | 6.471 |  | 16.800 | -3.576 |  | 16.800 | -2.328 |  | 16.800 | -6.281 |  | 16.800 | -6.847
16.900 | -4.187 |  | 16.900 | -3.651 |  | 16.900 | 6.465 |  | 16.900 | -3.520 |  | 16.900 | -2.281 |  | 16.900 | -6.247 |  | 16.900 | -6.813
17.000 | -4.250 |  | 17.000 | -3.621 |  | 17.000 | 6.467 |  | 17.000 | -3.465 |  | 17.000 | -2.235 |  | 17.000 | -6.227 |  | 17.000 | -6.784
17.100 | -4.318 |  | 17.100 | -3.591 |  | 17.100 | 6.462 |  | 17.100 | -3.411 |  | 17.100 | -2.194 |  | 17.100 | -6.194 |  | 17.100 | -6.749
17.200 | -4.376 |  | 17.200 | -3.564 |  | 17.200 | 6.463 |  | 17.200 | -3.352 |  | 17.200 | -2.150 |  | 17.200 | -6.170 |  | 17.200 | -6.717
17.300 | -4.444 |  | 17.300 | -3.540 |  | 17.300 | 6.462 |  | 17.300 | -3.301 |  | 17.300 | -2.112 |  | 17.300 | -6.145 |  | 17.300 | -6.688
17.400 | -4.503 |  | 17.400 | -3.522 |  | 17.400 | 6.462 |  | 17.400 | -3.241 |  | 17.400 | -2.096 |  | 17.400 | -6.116 |  | 17.400 | -6.653
17.500 | -4.567 |  | 17.500 | -3.497 |  | 17.500 | 6.465 |  | 17.500 | -3.197 |  | 17.500 | -2.091 |  | 17.500 | -6.097 |  | 17.500 | -6.627
17.600 | -4.627 |  | 17.600 | -3.476 |  | 17.600 | 6.461 |  | 17.600 | -3.152 |  | 17.600 | -2.077 |  | 17.600 | -6.065 |  | 17.600 | -6.592
17.700 | -4.679 |  | 17.700 | -3.452 |  | 17.700 | 6.460 |  | 17.700 | -3.101 |  | 17.700 | -2.045 |  | 17.700 | -6.027 |  | 17.700 | -6.566
17.800 | -4.740 |  | 17.800 | -3.430 |  | 17.800 | 6.477 |  | 17.800 | -3.005 |  | 17.800 | -2.011 |  | 17.800 | -5.996 |  | 17.800 | -6.534
17.900 | -4.786 |  | 17.900 | -3.395 |  | 17.900 | 6.482 |  | 17.900 | -2.878 |  | 17.900 | -1.979 |  | 17.900 | -5.926 |  | 17.900 | -6.498
18.000 | -4.845 |  | 18.000 | -3.353 |  | 18.000 | 6.470 |  | 18.000 | -2.759 |  | 18.000 | -1.938 |  | 18.000 | -5.850 |  | 18.000 | -6.467
18.100 | -4.891 |  | 18.100 | -3.316 |  | 18.100 | 6.428 |  | 18.100 | -2.641 |  | 18.100 | -1.899 |  | 18.100 | -5.766 |  | 18.100 | -6.430
18.200 | -4.943 |  | 18.200 | -3.276 |  | 18.200 | 6.469 |  | 18.200 | -2.539 |  | 18.200 | -1.865 |  | 18.200 | -5.695 |  | 18.200 | -6.398
18.300 | -4.996 |  | 18.300 | -3.244 |  | 18.300 | 6.552 |  | 18.300 | -2.437 |  | 18.300 | -1.825 |  | 18.300 | -5.625 |  | 18.300 | -6.366
18.400 | -5.042 |  | 18.400 | -3.206 |  | 18.400 | 6.556 |  | 18.400 | -2.354 |  | 18.400 | -1.794 |  | 18.400 | -5.558 |  | 18.400 | -6.318
18.500 | -5.093 |  | 18.500 | -3.175 |  | 18.500 | 6.456 |  | 18.500 | -2.276 |  | 18.500 | -1.753 |  | 18.500 | -5.499 |  | 18.500 | -6.271
18.600 | -5.143 |  | 18.600 | -3.147 |  | 18.600 | 6.430 |  | 18.600 | -2.208 |  | 18.600 | -1.719 |  | 18.600 | -5.443 |  | 18.600 | -6.217
18.700 | -5.184 |  | 18.700 | -3.125 |  | 18.700 | 6.424 |  | 18.700 | -2.107 |  | 18.700 | -1.684 |  | 18.700 | -5.398 |  | 18.700 | -6.176
18.800 | -5.232 |  | 18.800 | -3.104 |  | 18.800 | 6.436 |  | 18.800 | -1.948 |  | 18.800 | -1.650 |  | 18.800 | -5.355 |  | 18.800 | -6.136
18.900 | -5.267 |  | 18.900 | -3.084 |  | 18.900 | 6.433 |  | 18.900 | -1.755 |  | 18.900 | -1.617 |  | 18.900 | -5.319 |  | 18.900 | -6.092
19.000 | -5.309 |  | 19.000 | -3.065 |  | 19.000 | 6.427 |  | 19.000 | -1.566 |  | 19.000 | -1.586 |  | 19.000 | -5.285 |  | 19.000 | -6.057
19.100 | -5.336 |  | 19.100 | -3.049 |  | 19.100 | 6.414 |  | 19.100 | -1.367 |  | 19.100 | -1.554 |  | 19.100 | -5.256 |  | 19.100 | -6.011
19.200 | -5.370 |  | 19.200 | -3.034 |  | 19.200 | 6.405 |  | 19.200 | -1.168 |  | 19.200 | -1.528 |  | 19.200 | -5.226 |  | 19.200 | -5.977
19.300 | -5.400 |  | 19.300 | -3.022 |  | 19.300 | 6.419 |  | 19.300 | -0.989 |  | 19.300 | -1.495 |  | 19.300 | -5.202 |  | 19.300 | -5.936
19.400 | -5.427 |  | 19.400 | -3.007 |  | 19.400 | 6.431 |  | 19.400 | -0.816 |  | 19.400 | -1.468 |  | 19.400 | -5.177 |  | 19.400 | -5.898
19.500 | -5.453 |  | 19.500 | -2.994 |  | 19.500 | 6.436 |  | 19.500 | -0.631 |  | 19.500 | -1.438 |  | 19.500 | -5.157 |  | 19.500 | -5.865
19.600 | -5.481 |  | 19.600 | -2.981 |  | 19.600 | 6.445 |  | 19.600 | -0.475 |  | 19.600 | -1.412 |  | 19.600 | -5.137 |  | 19.600 | -5.825
19.700 | -5.509 |  | 19.700 | -2.971 |  | 19.700 | 6.451 |  | 19.700 | -0.307 |  | 19.700 | -1.381 |  | 19.700 | -5.118 |  | 19.700 | -5.792
19.800 | -5.529 |  | 19.800 | -2.961 |  | 19.800 | 6.458 |  | 19.800 | -0.154 |  | 19.800 | -1.350 |  | 19.800 | -5.100 |  | 19.800 | -5.755
19.900 | -5.548 |  | 19.900 | -2.952 |  | 19.900 | 6.459 |  | 19.900 | 0.000 |  | 19.900 | -1.325 |  | 19.900 | -5.083 |  | 19.900 | -5.708
20.000 | -5.571 |  | 20.000 | -2.943 |  | 20.000 | 6.459 |  | 20.000 | 0.139 |  | 20.000 | -1.296 |  | 20.000 | -5.067 |  | 20.000 | -5.678
20.100 | -5.590 |  | 20.100 | -2.934 |  | 20.100 | 6.457 |  | 20.100 | 0.280 |  | 20.100 | -1.273 |  | 20.100 | -5.054 |  | 20.100 | -5.640
20.200 | -5.607 |  | 20.200 | -2.924 |  | 20.200 | 6.457 |  | 20.200 | 0.417 |  | 20.200 | -1.244 |  |  |  |  | 20.200 | -5.611
20.300 | -5.618 |  | 20.300 | -2.917 |  | 20.300 | 6.456 |  | 20.300 | 0.538 |  | 20.300 | -1.224 |  |  |  |  | 20.300 | -5.576
20.400 | -5.630 |  | 20.400 | -2.909 |  | 20.400 | 6.459 |  | 20.400 | 0.668 |  | 20.400 | -1.210 |  |  |  |  | 20.400 | -5.545
20.500 | -5.637 |  | 20.500 | -2.904 |  | 20.500 | 6.459 |  | 20.500 | 0.794 |  | 20.500 | -1.205 |  |  |  |  | 20.500 | -5.511
20.600 | -5.643 |  | 20.600 | -2.896 |  | 20.600 | 6.458 |  | 20.600 | 0.903 |  | 20.600 | -1.208 |  |  |  |  | 20.600 | -5.476
20.700 | -5.652 |  | 20.700 | -2.890 |  | 20.700 | 6.461 |  |  |  |  | 20.700 | -1.214 |  |  |  |  | 20.700 | -5.444
20.800 | -5.651 |  | 20.800 | -2.884 |  | 20.800 | 6.459 |  |  |  |  | 20.800 | -1.221 |  |  |  |  | 20.800 | -5.411
20.900 | -5.646 |  | 20.900 | -2.878 |  | 20.900 | 6.459 |  |  |  |  |  |  |  |  |  |  | 20.900 | -5.380
21.000 | -5.635 |  | 21.000 | -2.872 |  | 21.000 | 6.461 |  |  |  |  |  |  |  |  |  |  | 21.000 | -5.353
21.100 | -5.625 |  | 21.100 | -2.866 |  | 21.100 | 6.461 |  |  |  |  |  |  |  |  |  |  | 21.100 | -5.324
21.200 | -5.608 |  | 21.200 | -2.862 |  | 21.200 | 6.459 |  |  |  |  |  |  |  |  |  |  | 21.200 | -5.298
21.300 | -5.592 |  | 21.300 | -2.856 |  | 21.300 | 6.460 |  |  |  |  |  |  |  |  |  |  | 21.300 | -5.267
21.400 | -5.577 |  | 21.400 | -2.852 |  | 21.400 | 6.460 |  |  |  |  |  |  |  |  |  |  | 21.400 | -5.241
21.500 | -5.552 |  | 21.500 | -2.843 |  | 21.500 | 6.461
21.600 | -5.528 |  | 21.600 | -2.840 |  | 21.600 | 6.459
21.700 | -5.492 |  | 21.700 | -2.835 |  | 21.700 | 6.459
21.800 | -5.453 |  |  |  |  | 21.800 | 6.460
21.900 | -5.418 |  |  |  |  | 21.900 | 6.462
22.000 | -5.374 |  |  |  |  | 22.000 | 4.422
22.100 | -5.343 |  |  |  |  | 22.100 | 3.029
22.200 | -5.298 |  |  |  |  | 22.200 | 2.014
22.300 | -5.261 |  |  |  |  | 22.300 | 1.343
22.400 | -5.220 |  |  |  |  | 22.400 | 0.926
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

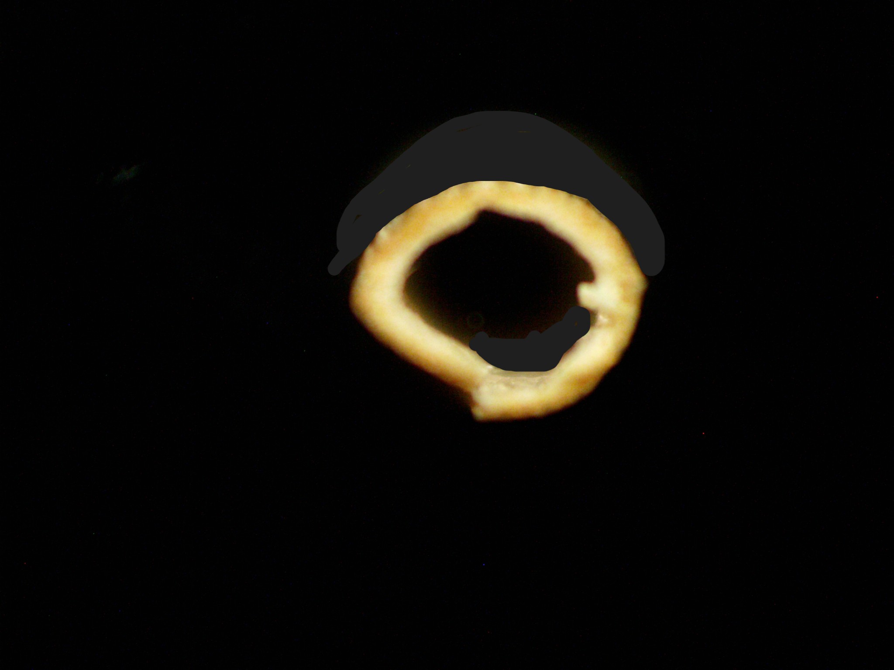
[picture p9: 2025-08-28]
CollectedData/MaterialTesting/CrossSectionImages/D258.jpg

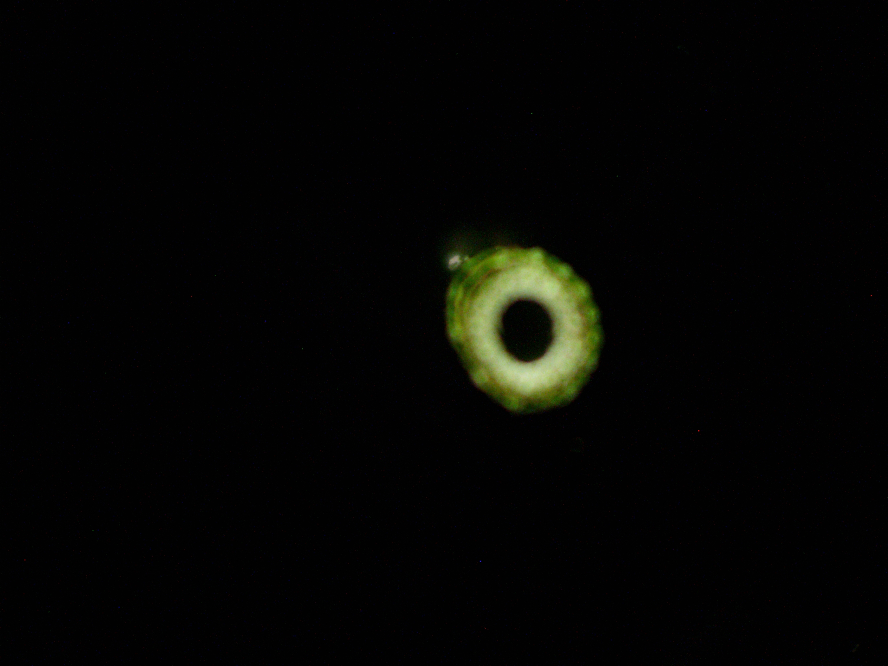
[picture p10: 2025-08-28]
CollectedData/MaterialTesting/CrossSectionImages/L123.jpg

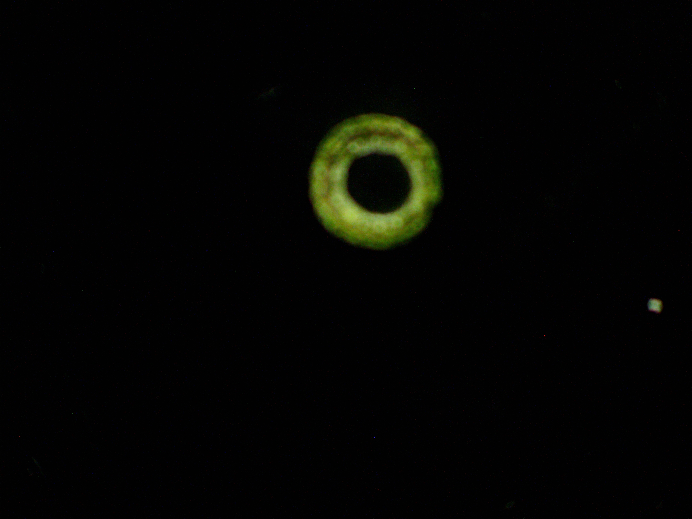
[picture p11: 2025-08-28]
CollectedData/MaterialTesting/CrossSectionImages/L117.jpg

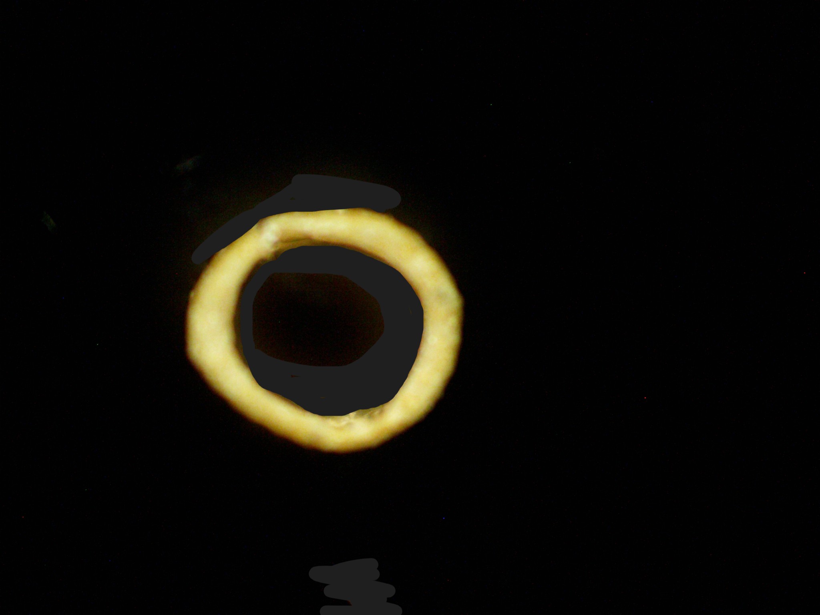
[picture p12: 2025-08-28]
CollectedData/MaterialTesting/CrossSectionImages/D1602.jpg

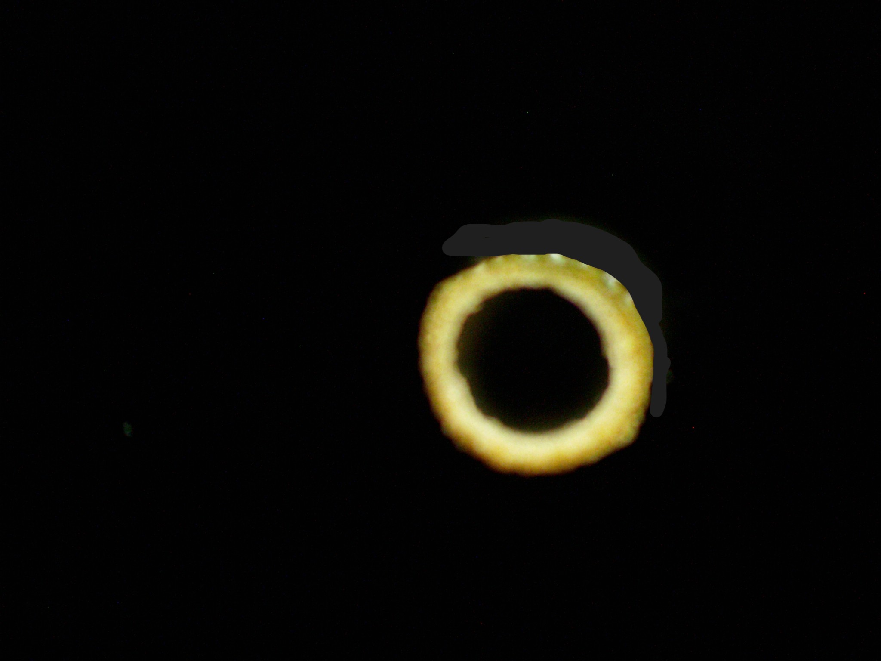
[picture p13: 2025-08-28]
CollectedData/MaterialTesting/CrossSectionImages/D178.jpg

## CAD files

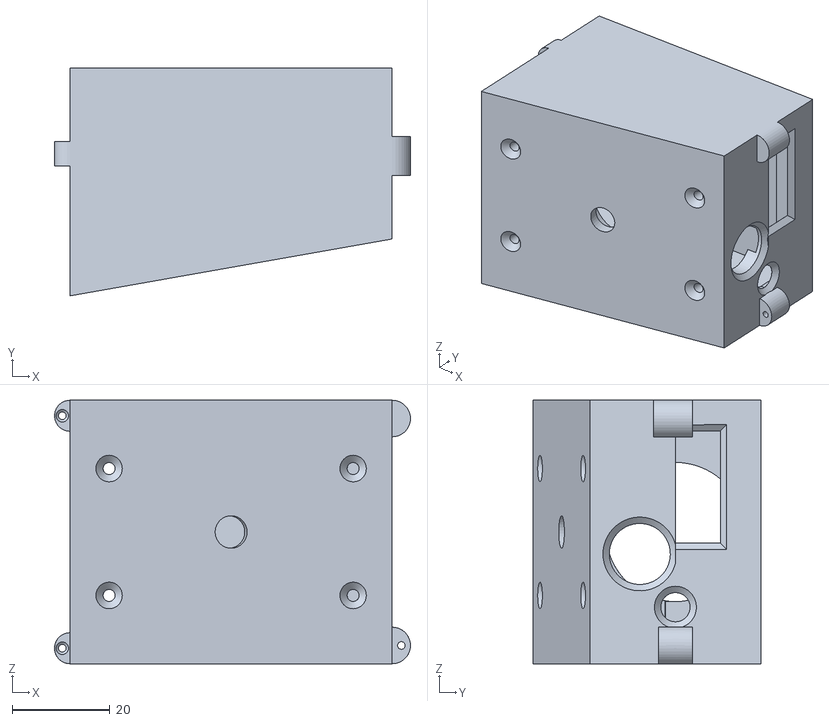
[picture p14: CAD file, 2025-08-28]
PhysicalDesign/modelling/CameraGSU3Hold.stl
72.9 x 46.7 x 54.0

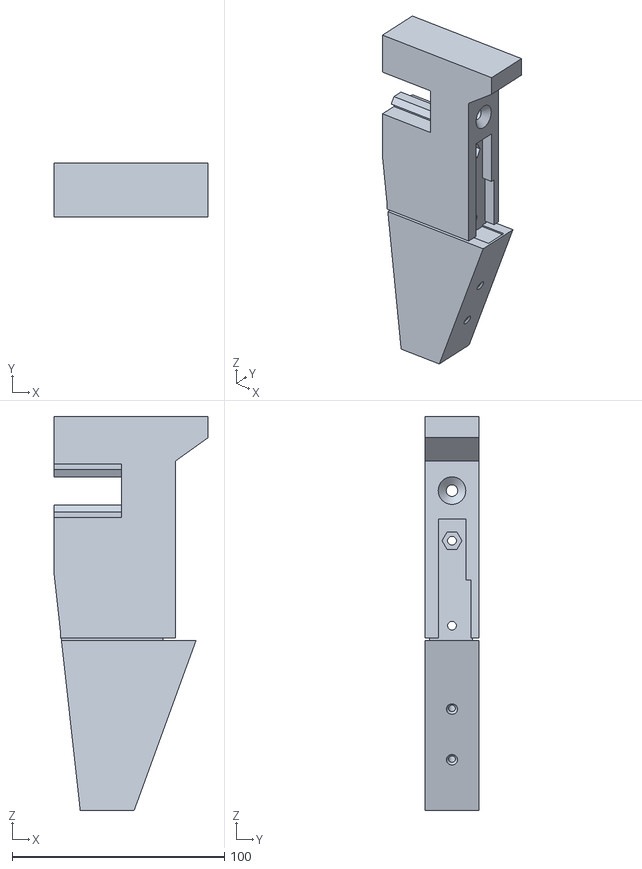
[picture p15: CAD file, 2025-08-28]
PhysicalDesign/modelling/LoadCell-Right.stl
72.5 x 25.4 x 185.5

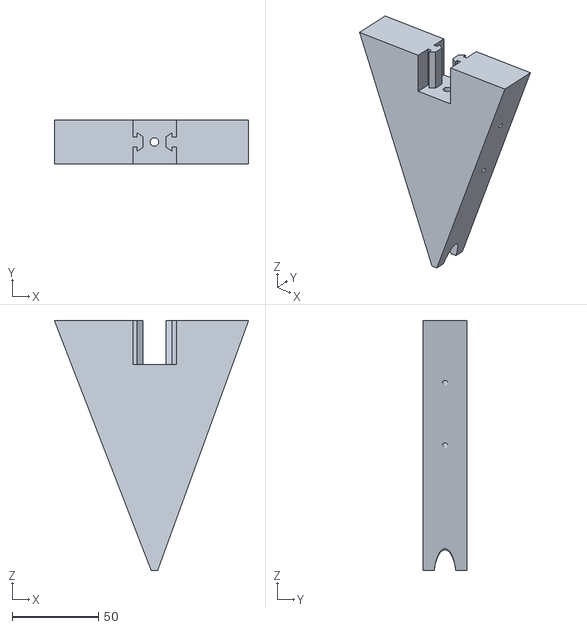
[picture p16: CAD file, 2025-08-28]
PhysicalDesign/modelling/TopPoint.stl
112.7 x 25.4 x 145.0

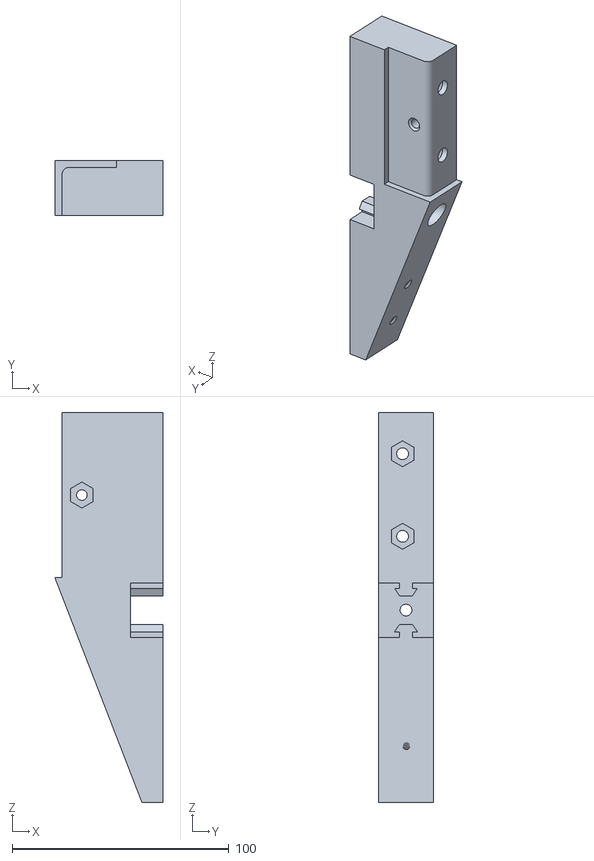
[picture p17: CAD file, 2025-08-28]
PhysicalDesign/modelling/TriangleArmAttachment-Left.stl
50.0 x 25.4 x 180.0

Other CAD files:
PhysicalDesign/modelling/ExternalArmSeparator.ipt
PhysicalDesign/modelling/MainTriangleFrameParts.ipt
PhysicalDesign/modelling/Total_Assembly.iam

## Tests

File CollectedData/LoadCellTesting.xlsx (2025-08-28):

Metric | Load Cell Data |  | 0.446475607
1 | 0.4639047279 | 0.01742912097
2 | 0.4633893851 | 0.01691377815
3 | 0.4636018976 | 0.01712629065
4 | 0.4627943501 | 0.01631874314
5 | 0.4641119276 | 0.01763632066
6 | 0.4634690773 | 0.01699347034
7 | 0.4620186795 | 0.0155430725
8 | 0.4611208141 | 0.01464520718
9 | 0.4598829288 | 0.01340732184
10 | 0.4603238922 | 0.01384828529
11 | 0.4610729988 | 0.01459739186
12 | 0.4597554213 | 0.01327981434
13 | 0.4588256791 | 0.01235007214
14 | 0.4585866025 | 0.01211099557
15 | 0.4588788072 | 0.01240320027
16 | 0.4593357091 | 0.01286010215
17 | 0.4594260269 | 0.01295041996
18 | 0.45905413 | 0.01257852308
19 | 0.4559461347 | 0.009470527719
20 | 0.4556486172 | 0.009173010214
21 | 0.458772551 | 0.01229694401
22 | 0.4585866025 | 0.01211099557
23 | 0.4586981716 | 0.01222256464
24 | 1.174679359 | 0.7282037525
25 | 0.8700267475 | 0.4235511405
26 | 0.4843643692 | 0.03788876223
27 | 0.4766289141 | 0.03015330711
28 | 0.4768361138 | 0.0303605068
29 | 0.4796094019 | 0.03313379497
30 | 0.4778561738 | 0.03138056682
31 | 0.4763207709 | 0.02984516398
32 | 0.4743603431 | 0.02788473614
33 | 0.4718048802 | 0.02532927328
34 | 0.4722830334 | 0.02580742642
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

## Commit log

2025-08-28 Final poster created with materials and data from this repo!
2025-08-28 Some of these files are purely visual, not printable
    [Camera.ipt, FrameParts.ipt, LoadCellIfuckedUp.stl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]
2025-08-28 A visual reference for machining
    [TotalDesign_Assembly.iam]
2025-08-28 A visual for machining
    No 3d printed parts
    [ExternalArm.ipt]
2025-08-28 Visual Reference of Main Triangle Design
    [TriangleFrame.ipt]
2025-08-28 STL file for 3D printed of triangle
    [LoadCell-Right.stl, TopPoint.stl, TriangleArmAttachment-Left.stl]
2025-08-28 Casing for Grasshopper Camera used
    [CameraGSU3Hold.stl]
2025-08-28 STL Files for 3D printed parts
    [LoadCell-Right.stl, TopPoint.stl, TriangleArmAttachment-Left.stl]
2025-08-28 Visual reference for machining purposes
    [MainTriangleFrameParts.ipt]
2025-08-28 Casing/mount for Grasshopper camera
    [CameraGSU3Hold.stl]
2025-08-28 Printable STLs and Visual References
2025-08-28 uses load and area to calculate parameters
    [MaterialTestingAnalysis.xlsx]
2025-08-28 Materials Testing excel sheet added
    [MaterialsTesting.xlsx]
2025-08-28 Updated Material testing analysis sheet
    [MaterialsTestingAnalysis.xlsx]
